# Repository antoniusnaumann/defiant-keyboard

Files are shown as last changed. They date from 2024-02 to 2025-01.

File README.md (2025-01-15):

# Defiant Keyboard
## Firmware
You can find the firmware here: https://github.com/antoniusnaumann/defiant-zmk

## Bill of Materials
(Diodes are not included, order PCBs with diodes assembled)

| Component | Product | Quantity | Link |
|---|---|---|---|
| Hotswap Socket | Gateron KS-33 Hotswap Socket | 44 | https://www.aliexpress.com/item/1005006042596309.html |
| LiPo Battery | LP401230, 3,7V, ~100mAh |  2 | https://eckstein-shop.de/LiPo-Akku-Lithium-Ion-Polymer-Batterie-37V-105mAh-mit-JST-PHR-2-Stecker-LP401230 |
| Connector | JST-PH 2.0 2 Pin Angled |  2 | https://www.digikey.de/de/products/detail/jst-sales-america-inc/S2B-PH-K-S/926626 | 
| Controller | Seeedstudio XIAO nrf52840 |  2 | https://www.seeedstudio.com/Seeed-XIAO-BLE-nRF52840-p-5201.html | 
| EVA Foam* | 2mm and 1mm |  1 each  | |

*EVA foam is optional and needs to be cut with a laser cutter. See SVG files in case/

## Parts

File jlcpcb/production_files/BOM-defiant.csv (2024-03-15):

Comment | Designator | Footprint | LCSC
D | D1,D10,D11,D12,D13,D14,D15,D16,D17,D18,D19,D2,D20,D22,D23,D3,D4,D5,D6,D7,D8,D9 | D_SOD-123 | C81598
SW_PUSH | T0 | SW_Gateron_LowProfile_HotSwap_PTH_Reversible
SW_PUSH | T2 | SW_Gateron_LowProfile_HotSwap_PTH_Reversible
SW_PUSH | C5R2 | SW_Gateron_LowProfile_HotSwap_PTH_Reversible
SW_PUSH | T4 | SW_Gateron_LowProfile_HotSwap_PTH_Reversible
SW_PUSH | T1 | SW_Gateron_LowProfile_HotSwap_PTH_Reversible
SW_PUSH | T3 | SW_Gateron_LowProfile_HotSwap_PTH_Reversible
SW_PUSH | C5R3 | SW_Gateron_LowProfile_HotSwap_PTH_Reversible
SW_PUSH | C3R1 | SW_Gateron_LowProfile_HotSwap_PTH_Reversible
SW_PUSH | C3R3 | SW_Gateron_LowProfile_HotSwap_PTH_Reversible
SW_PUSH | C2R3 | SW_Gateron_LowProfile_HotSwap_PTH_Reversible
SW_PUSH | C3R2 | SW_Gateron_LowProfile_HotSwap_PTH_Reversible
SW_PUSH | C0R2 | SW_Gateron_LowProfile_HotSwap_PTH_Reversible
SW_PUSH | C0R1 | SW_Gateron_LowProfile_HotSwap_PTH_Reversible
SW_PUSH | C0R3 | SW_Gateron_LowProfile_HotSwap_PTH_Reversible
SW_PUSH | C4R2 | SW_Gateron_LowProfile_HotSwap_PTH_Reversible
SW_PUSH | C1R3 | SW_Gateron_LowProfile_HotSwap_PTH_Reversible
SW_PUSH | C2R2 | SW_Gateron_LowProfile_HotSwap_PTH_Reversible
SW_PUSH | C2R1 | SW_Gateron_LowProfile_HotSwap_PTH_Reversible
SW_PUSH | C1R2 | SW_Gateron_LowProfile_HotSwap_PTH_Reversible
SW_PUSH | C4R3 | SW_Gateron_LowProfile_HotSwap_PTH_Reversible
SW_PUSH | C1R1 | SW_Gateron_LowProfile_HotSwap_PTH_Reversible
SW_PUSH | C4R1 | SW_Gateron_LowProfile_HotSwap_PTH_Reversible
Seeed Studio XIAO BLE | U1 | XIAO-nRF52840-Sense-14P-2.54-21X17.8MM_Reduced_Pins
SW_Push | SW1 | SW_SPST_TL3342
Conn_01x02_Pin | J1 | Lipo Connector
SW_DP3T | SW3 | SW_CuK_JS202011AQN_DPDT_Angled
SW_Push | SW2 | SW_SPST_TL3342

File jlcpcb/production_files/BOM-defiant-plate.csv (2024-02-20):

Comment | Designator | Footprint | LCSC
SW_PUSH | T0 | SW_Gateron_LowProfile_Plate
SW_PUSH | T2 | SW_Gateron_LowProfile_Plate
SW_PUSH | C5R2 | SW_Gateron_LowProfile_Plate
SW_PUSH | T4 | SW_Gateron_LowProfile_Plate
SW_PUSH | T1 | SW_Gateron_LowProfile_Plate
SW_PUSH | T3 | SW_Gateron_LowProfile_Plate
SW_PUSH | C5R3 | SW_Gateron_LowProfile_Plate
SW_PUSH | C3R1 | SW_Gateron_LowProfile_Plate
SW_PUSH | C3R3 | SW_Gateron_LowProfile_Plate
SW_PUSH | C2R3 | SW_Gateron_LowProfile_Plate
SW_PUSH | C3R2 | SW_Gateron_LowProfile_Plate
SW_PUSH | C0R2 | SW_Gateron_LowProfile_Plate
SW_PUSH | C0R1 | SW_Gateron_LowProfile_Plate
SW_PUSH | C0R3 | SW_Gateron_LowProfile_Plate
SW_PUSH | C4R2 | SW_Gateron_LowProfile_Plate
SW_PUSH | C1R3 | SW_Gateron_LowProfile_Plate
SW_PUSH | C2R2 | SW_Gateron_LowProfile_Plate
SW_PUSH | C2R1 | SW_Gateron_LowProfile_Plate
SW_PUSH | C1R2 | SW_Gateron_LowProfile_Plate
SW_PUSH | C4R3 | SW_Gateron_LowProfile_Plate
SW_PUSH | C1R1 | SW_Gateron_LowProfile_Plate
SW_PUSH | C4R1 | SW_Gateron_LowProfile_Plate

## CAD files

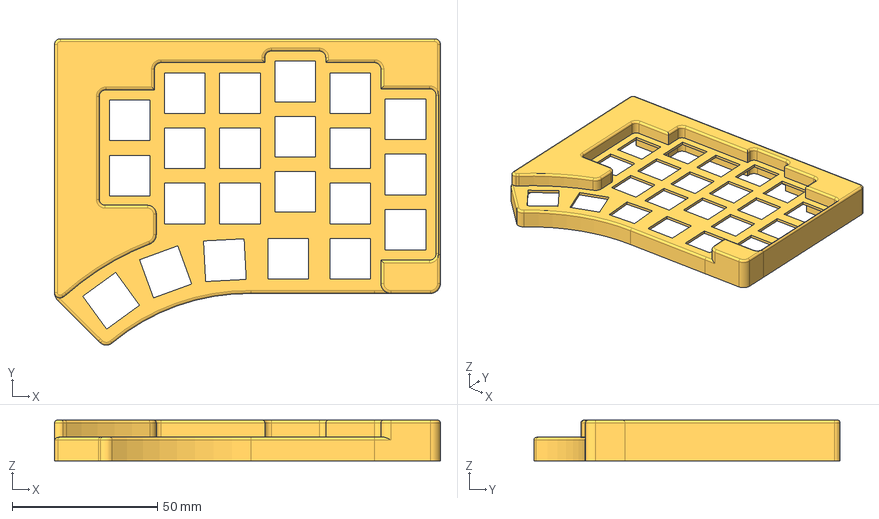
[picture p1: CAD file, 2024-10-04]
case/defiant_Case v2.step
133.0 x 105.6 x 14.1 mm

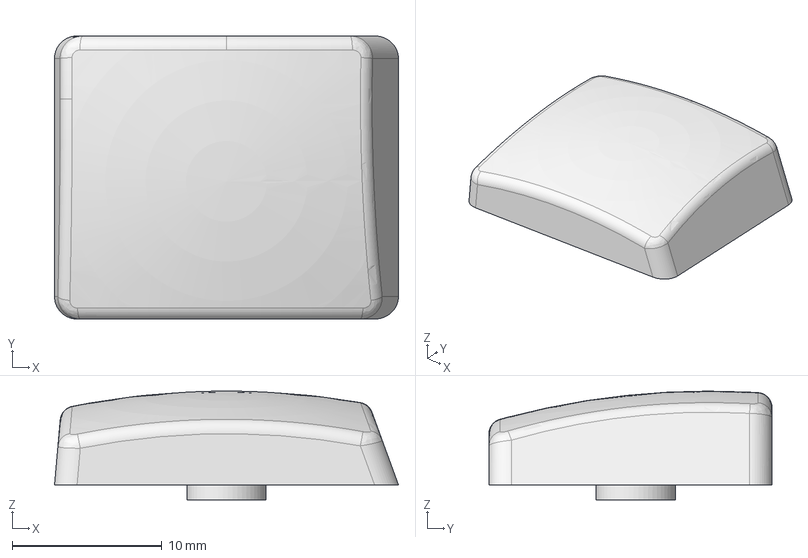
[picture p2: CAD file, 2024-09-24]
thumbkeys/defiant-thumb-smash.step
22.9 x 18.9 x 7.25 mm

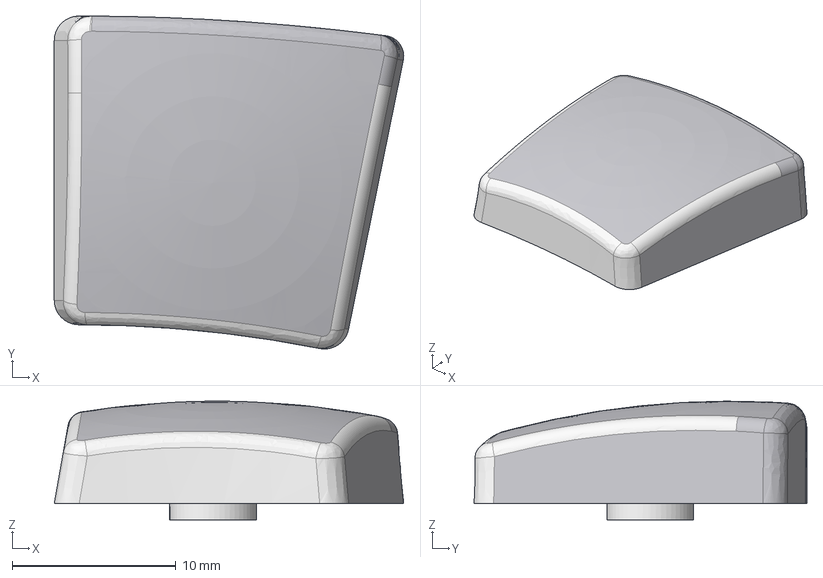
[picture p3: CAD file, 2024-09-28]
thumbkeys/left/defiant_Thumb Inner.step
21.4 x 20.4 x 7.25 mm

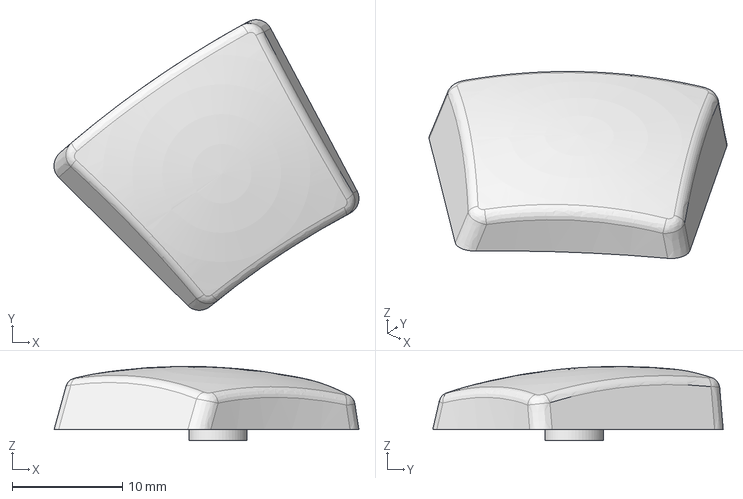
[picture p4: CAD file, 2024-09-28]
thumbkeys/right/defiant_Thumb Outer.step
27.7 x 26.4 x 6.75 mm

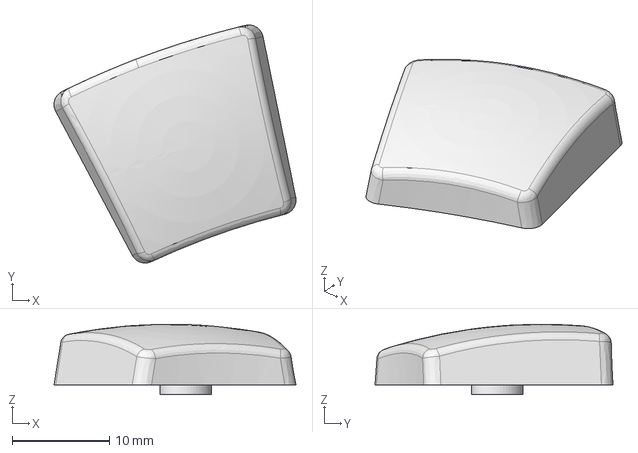
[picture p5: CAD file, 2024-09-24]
thumbkeys/defiant-thumb-home.step
24.9 x 24.5 x 7.25 mm

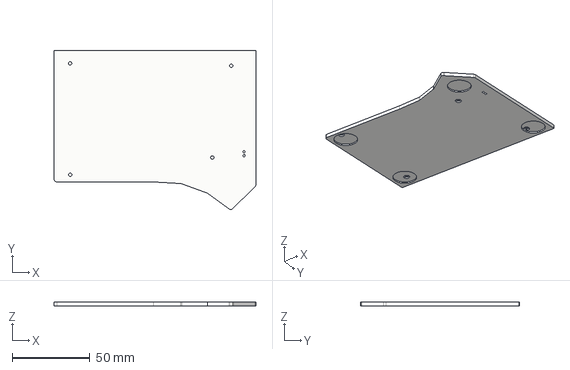
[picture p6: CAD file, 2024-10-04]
case/defiant_Bottom Plate Left.step
129.6 x 102.0 x 2.50 mm

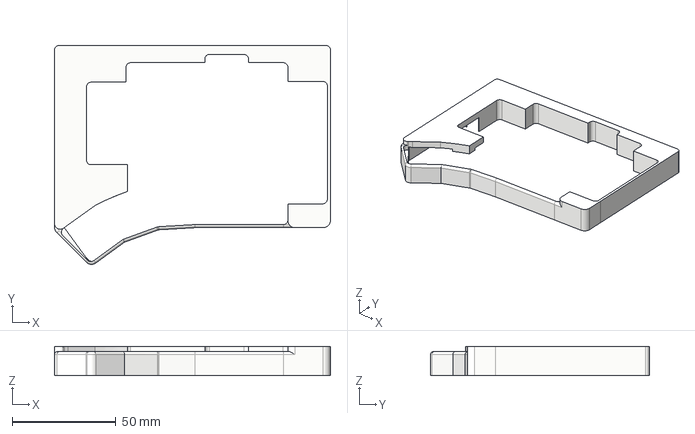
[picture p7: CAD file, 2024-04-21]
case/case-right.step
133.0 x 105.4 x 14.1 mm

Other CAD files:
case/defiant_Case v2 Left.step
thumbkeys/left/defiant_Thumb Outer.step
thumbkeys/right/defiant_Thumb Home.step
thumbkeys/left/defiant_Thumb Smash.step
thumbkeys/right/defiant_Thumb Smash.step
case/defiant_Bottom Plate.step
thumbkeys/left/defiant_Thumb Home.step
thumbkeys/right/defiant_Thumb Inner.step

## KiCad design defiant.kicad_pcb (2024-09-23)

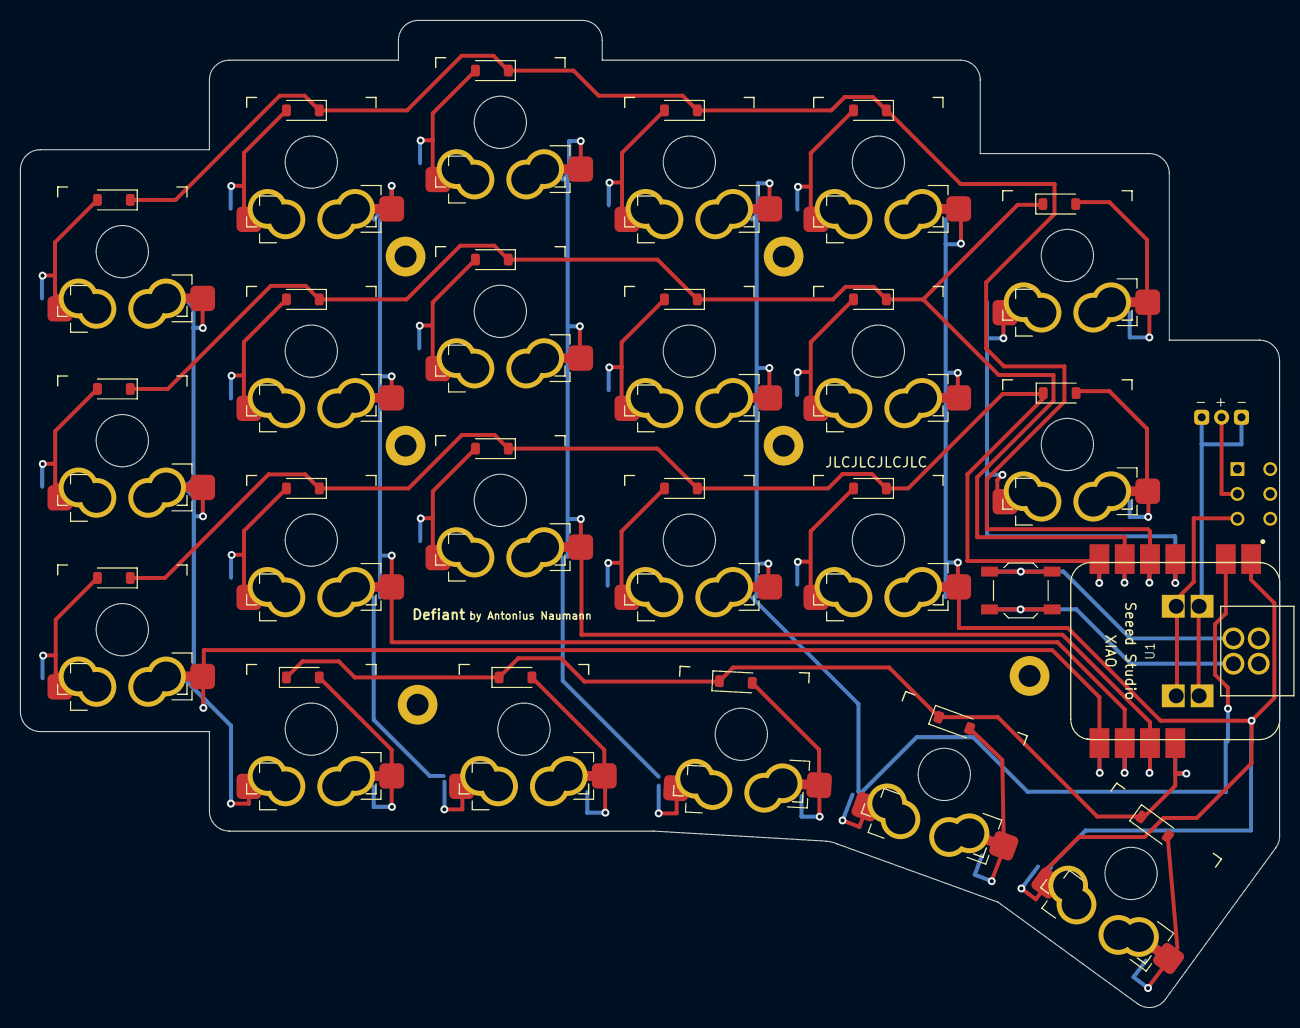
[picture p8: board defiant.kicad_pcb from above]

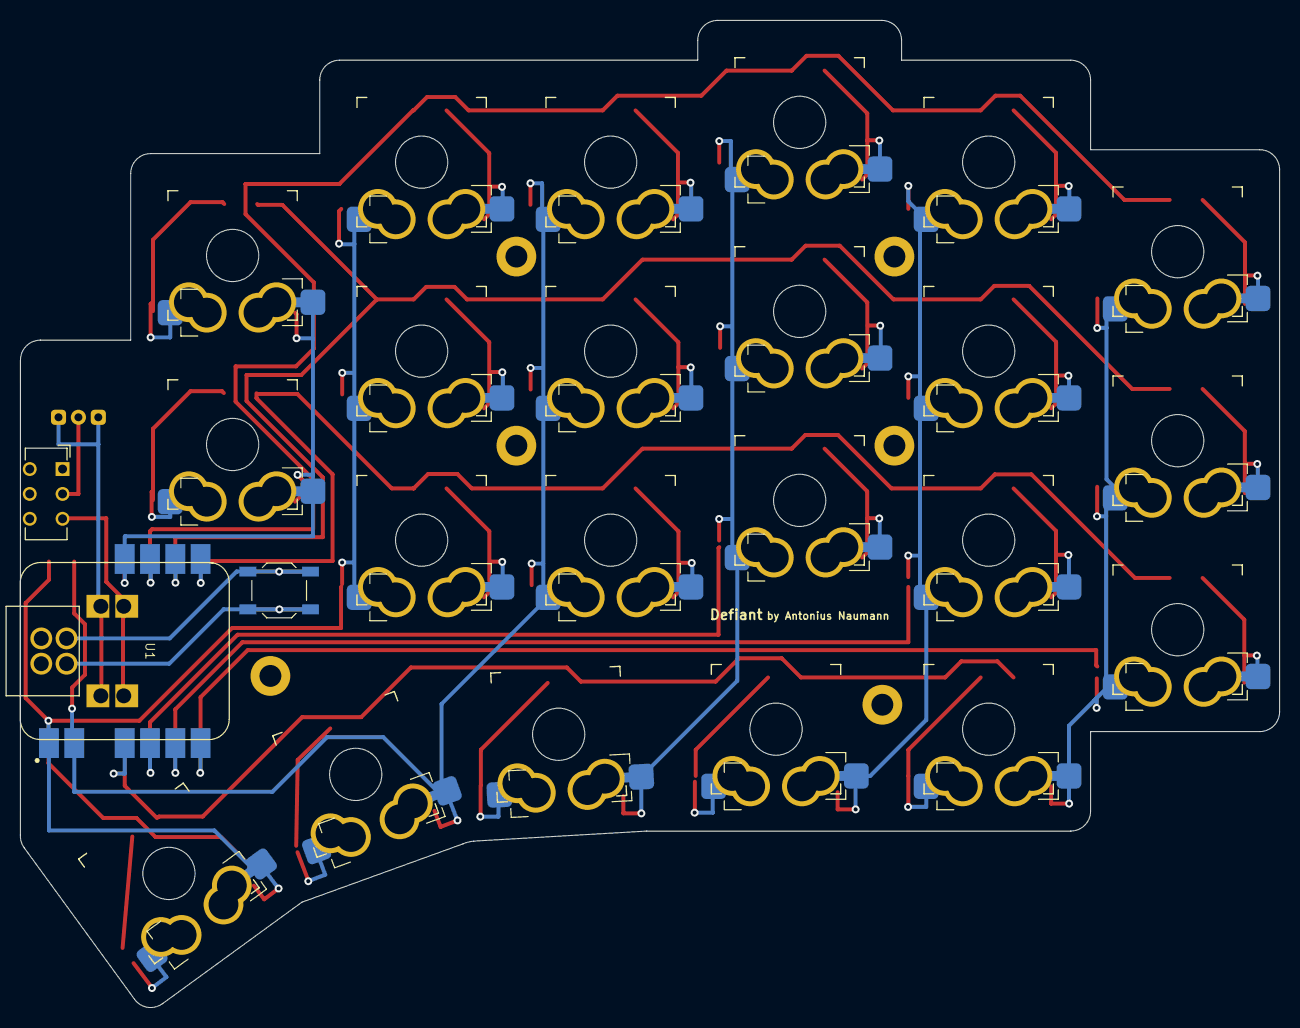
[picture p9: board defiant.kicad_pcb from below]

Board: 2 copper layers, 126.6 x 99.2 mm, 49 parts (17 on the bottom side), 37 nets.

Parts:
C0R1, C0R2, C0R3, C1R1, C1R2, C1R3, C2R1, C2R2, C2R3, C3R1, C3R2, C3R3, C4R1, C4R2, C4R3, C5R2, C5R3: SW_PUSH; SW_Gateron_LowProfile_HotSwap_PTH_Reversible
D1, D2, D3, D4, D5, D6, D7, D8, D9, D10, D11, D12, D13, D14, D15, D16, D17, D18, D19, D20, D22, D23: D; D_SOD-123
J1: Conn_01x02_Pin; Lipo Connector
SW1, SW2: SW_Push; SW_SPST_TL3342
SW3: SW_DP3T; SW_CuK_JS202011AQN_DPDT_Angled
T0, T1, T2, T3, T4: SW_PUSH; SW_Gateron_LowProfile_HotSwap_PTH_Reversible
U1: Seeed Studio XIAO BLE; XIAO-nRF52840-Sense-14P-2.54-21X17.8MM_Reduced_Pins

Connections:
unnamed: C0R1.2, D1.2 (A)
unnamed: C0R2.2, D2.2 (A)
unnamed: C0R3.2, D3.2 (A)
unnamed: D4.2 (A), T0.2
unnamed: C1R1.2, D5.2 (A)
unnamed: C1R2.2, D6.2 (A)
unnamed: C1R3.2, D7.2 (A)
unnamed: D8.2 (A), T1.2
unnamed: C2R1.2, D9.2 (A)
unnamed: C2R2.2, D10.2 (A)
unnamed: C2R3.2, D11.2 (A)
unnamed: D12.2 (A), T2.2
unnamed: C3R1.2, D13.2 (A)
unnamed: C3R2.2, D14.2 (A)
unnamed: C3R3.2, D15.2 (A)
unnamed: D16.2 (A), T3.2
unnamed: C4R1.2, D17.2 (A)
unnamed: C4R2.2, D18.2 (A)
unnamed: C4R3.2, D19.2 (A)
unnamed: D20.2 (A), T4.2
unnamed: C5R2.2, D22.2 (A)
unnamed: C5R3.2, D23.2 (A)
unnamed: J1.1, U1.21 (BAT-)
unnamed: J1.2, SW3.2
unnamed: SW1.2, SW2.2, U1.20 (GND)
unnamed: SW3.3, U1.22 (BAT+)
unnamed: SW1.1, SW2.1, U1.19 (RESET)
col0: C0R1.1, C0R2.1, C0R3.1, T0.1, U1.8 (PB09_A7_D7_RX)
col1: C1R1.1, C1R2.1, C1R3.1, T1.1, U1.9 (PA7_A8_D8_SCK)
col2: C2R1.1, C2R2.1, C2R3.1, T2.1, U1.10 (PA5_A9_D9_MISO)
col3: C3R1.1, C3R2.1, C3R3.1, T3.1, U1.2 (PA4_A1_D1)
col4: C4R1.1, C4R2.1, C4R3.1, T4.1, U1.1 (PA02_A0_D0)
col5: C5R2.1, C5R3.1, U1.4 (PA11_A3_D3)
row0: D1.1 (K), D5.1 (K), D9.1 (K), D13.1 (K), D17.1 (K), U1.5 (PA8_A4_D4_SDA)
row1: D2.1 (K), D6.1 (K), D10.1 (K), D14.1 (K), D18.1 (K), D22.1 (K), U1.6 (PA9_A5_D5_SCL)
row2: D3.1 (K), D7.1 (K), D11.1 (K), D15.1 (K), D19.1 (K), D23.1 (K), U1.7 (PB08_A6_D6_TX)
row3: D4.1 (K), D8.1 (K), D12.1 (K), D16.1 (K), D20.1 (K), U1.11 (PA6_A10_D10_MOSI)

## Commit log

2024-02-17 Init repository
    [defiant.kicad_pcb, defiant.kicad_sch]
2024-02-17 Change thumb pad to regular keys
    [defiant.kicad_pcb, defiant.kicad_sch]
2024-02-17 Move home thumb key up
    [defiant.kicad_pcb]
2024-02-18 Update footprints
    [defiant.kicad_pcb, defiant.kicad_sch]
2024-02-18 Add power switch and reset button
    [defiant.kicad_pcb, defiant.kicad_sch]
2024-02-18 Create JLCPCB production files
    [BOM-defiant.csv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]
2024-02-18 Add defiant plate files
    [defiant-CuBottom.gbr, defiant-CuTop.gbr, defiant-EdgeCuts.gbr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]
2024-02-19 Add footprint for laser cut plate with 0.1mm kerf correction
    [defiant.kicad_pcb]
2024-02-19 Add exact keycap boundary to switch footprint
    [defiant.kicad_pcb]
2024-02-19 Change thumb keycap bounds to 1.25u and 1.75u
    [defiant.kicad_pcb]
2024-02-20 Experimental: Tighten thumb key placing
    [BOM-defiant-plate.csv, BOM-defiant.csv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]
2024-02-29 Move pinky column down by 1mm
    [defiant-plate.kicad_pcb, defiant.kicad_pcb]
2024-03-07 Replace XIAO BLE handsolder footprint with SMD solder footprint
    [defiant.kicad_pcb]
2024-03-14 Change pcb lane width to 0.4mm
    [defiant.kicad_pcb]
2024-03-14 Move vias out of pads
    [defiant.kicad_pcb]
2024-03-15 Update production files
    [BOM-defiant.csv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]
2024-04-21 Add exported case models
    [bottom-plate-left.3mf, bottom-plate-left.step, bottom-plate-right.3mf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]
2024-04-21 Add svgs for cutting bottom plate foam
2024-04-28 Update silk screen
    [defiant.kicad_pcb]
2024-05-15 Add custom thumb key models
    [defiant-thumb-home.step, defiant-thumb-inner.step, defiant-thumb-outer.step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]
2024-05-15 Fix power switch wiring
    [defiant.kicad_pcb, defiant.kicad_sch]
2024-09-23 Update thumb keycaps to not collide with standard keycaps
    [Defiant Thumb Collection_Thumb Home.step, Defiant Thumb Collection_Thumb Inner.step, Defiant Thumb Collection_Thumb Outer.step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]
2024-09-24 Add version of bottom plate with reset button hole
    [Defiant Thumb Collection_Thumb Home.step, Defiant Thumb Collection_Thumb Inner.step, Defiant Thumb Collection_Thumb Outer.step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]
2024-09-28 Update thumb keycaps with signifiers
    [defiant-thumb-inner.step, defiant-thumb-outer.step, defiant_Thumb Home.step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]
2024-10-01 Update bottom plates
    [bottom-plate-left.3mf, bottom-plate-left.step, bottom-plate-right-reset-hole.step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]
2024-10-01 Add v2 case with integrated plate
    [defiant-case-v2-right.step, defiant_Case v2 Left.step, defiant_Case v2.step]
2024-10-04 Add reset pin holes to bottom plates
    [bottom-plate-star-trek.3mf, defiant_Bottom Plate Left.step, defiant_Bottom Plate.step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]
2025-01-15 Add BOM
2025-01-27 Add plate foam
